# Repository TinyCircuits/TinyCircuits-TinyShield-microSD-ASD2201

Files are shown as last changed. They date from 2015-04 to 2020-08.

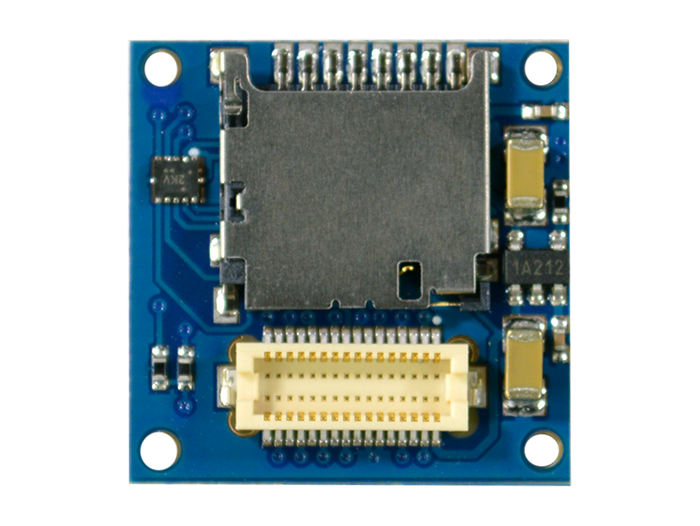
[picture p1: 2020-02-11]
images/ASD2201-R-Tutorial-Image-01.png

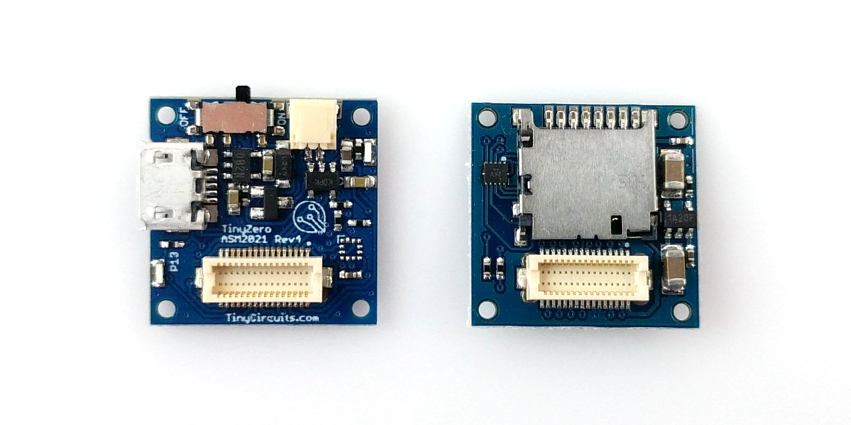
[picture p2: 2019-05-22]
images/ASD2201-R-Tutorial-Image-02.jpg

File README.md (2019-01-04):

# TinyCircuits TinyShield microSD Adapter Board
# ASD2201 Rev2

The design files are located under design_files/ for the TinyCircuits ASD2201 Rev 2 PCB.  This is a TinyShield board that has a microSD connector, local power supply and level shifters to connect to a microSD card.

Format is in Cadsoft Eagle format - Eagle version 6.2 was used for the original design.

For more infomation on this, check out the product page at TinyCircuits.com: https://tinycircuits.com/collections/memory/products/microsd-tinyshield

# License:

Design by TinyCircuits.
All design files are released under the Creative Commons Attribution Share-Alike 3.0 License, see the following link for details: http://creativecommons.org/licenses/by-sa/3.0

All text above must be included in any redistribution or derived design

This project uses designs and concepts developed as part of the Arduino project and the LilyPad project.  The TinyCircuits design files themselves (schematics, PCB and libraries) are not directly derived from these works' design files and have been created new, however the concepts and basic architecture behind the TinyDuino and TinyLily products are derived and we thank the hard work of the organizations below for their contributions to open-source hardware:
  
Original Arduino Uno Design by Team Arduino

LilyPad Arduino Design by Leah Buechley and Sparkfun Electronics

Please support the open-source hardware community

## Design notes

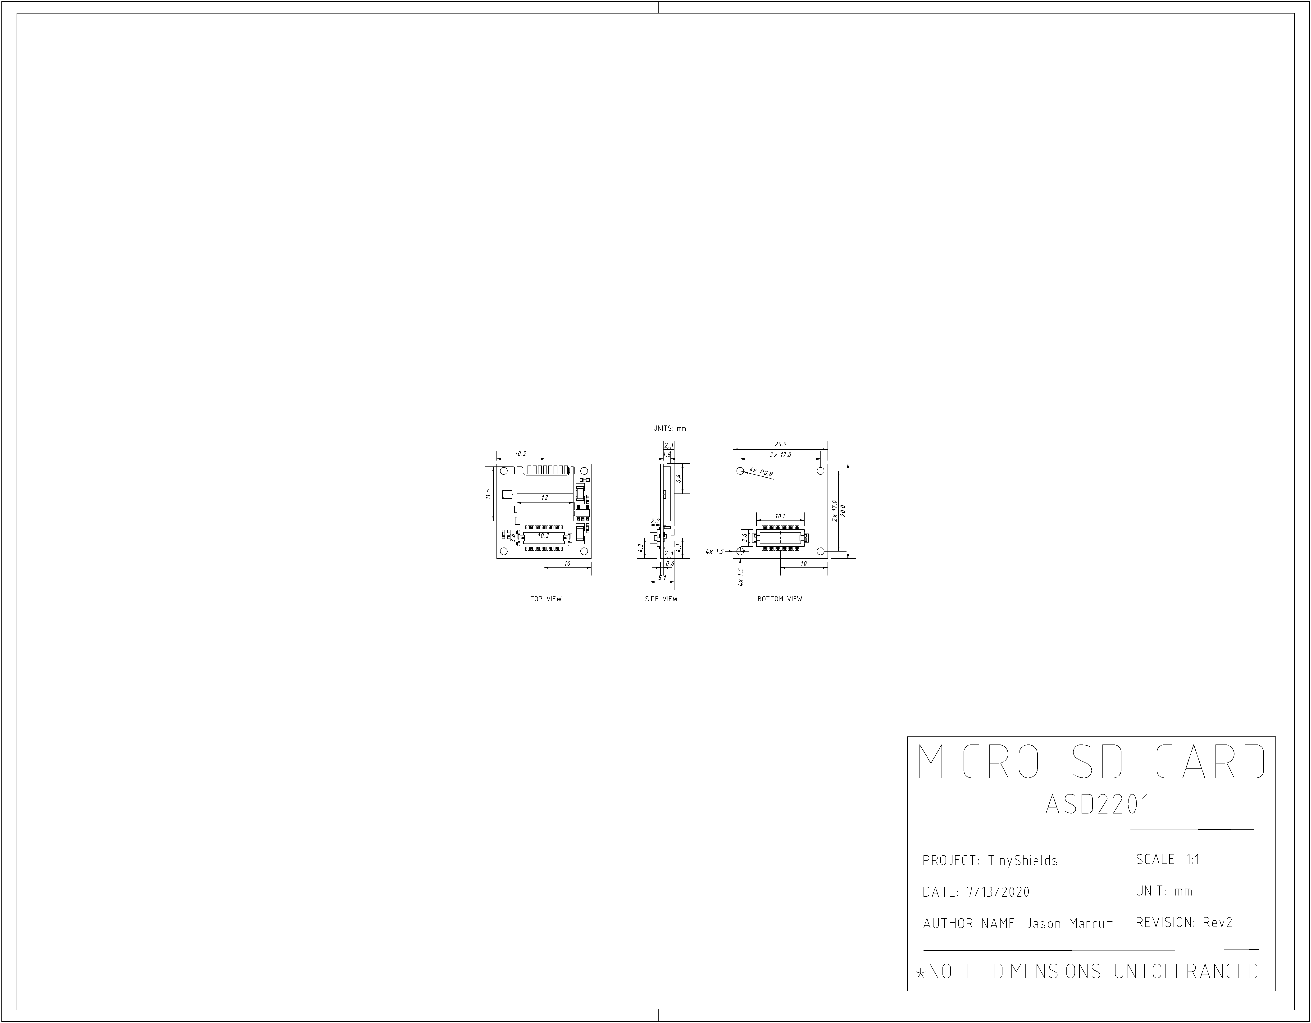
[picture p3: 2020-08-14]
cad/TinyShield_SDCARD_ASD2201_REV2-DETAILED_DRAWING-PNG.png

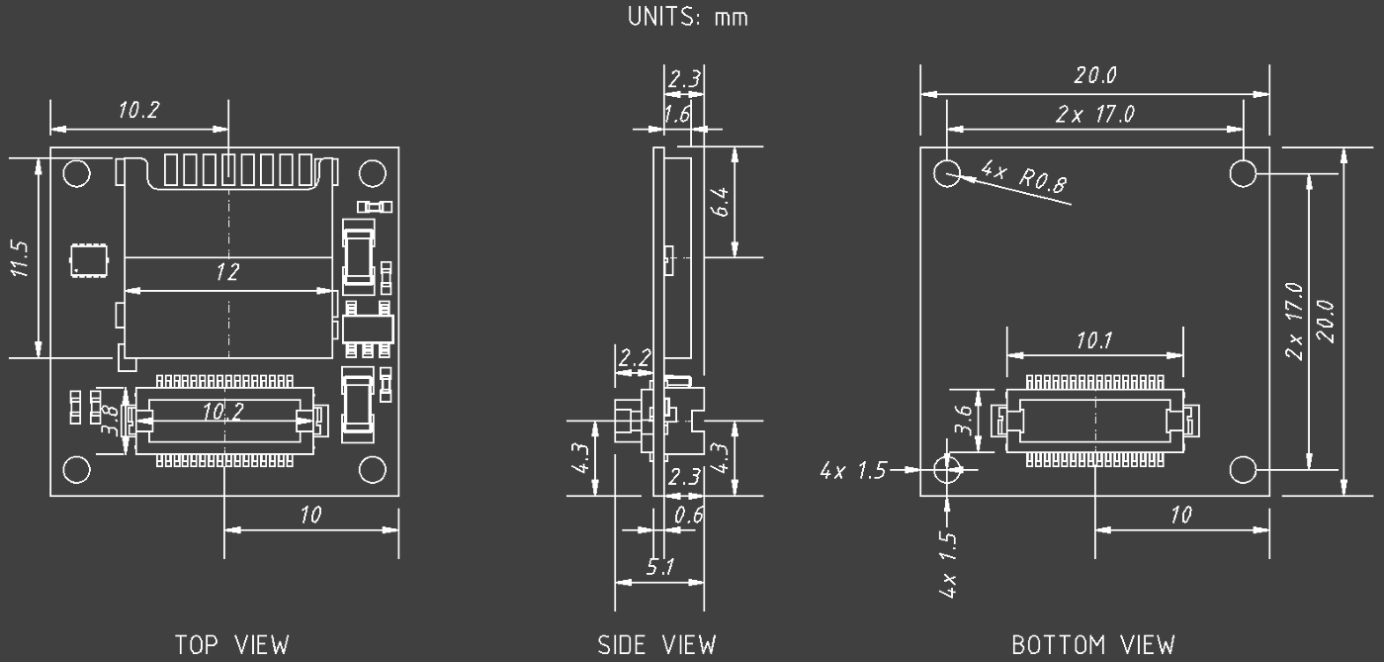
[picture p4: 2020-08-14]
cad/TinyShield_SDCARD_ASD2201_REV2-DETAILED_DRAWING_COMPACT-PNG.png

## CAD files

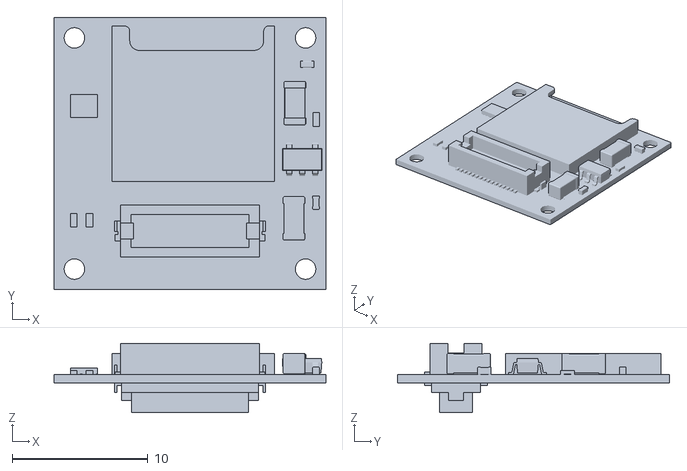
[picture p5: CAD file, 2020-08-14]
cad/TinyShield_SDCARD_ASD2201_REV2-STL.stl
20.0 x 20.0 x 5.10

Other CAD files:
cad/TinyShield_SDCARD_ASD2201_REV2-DETAILED_DRAWING-DXF.dxf

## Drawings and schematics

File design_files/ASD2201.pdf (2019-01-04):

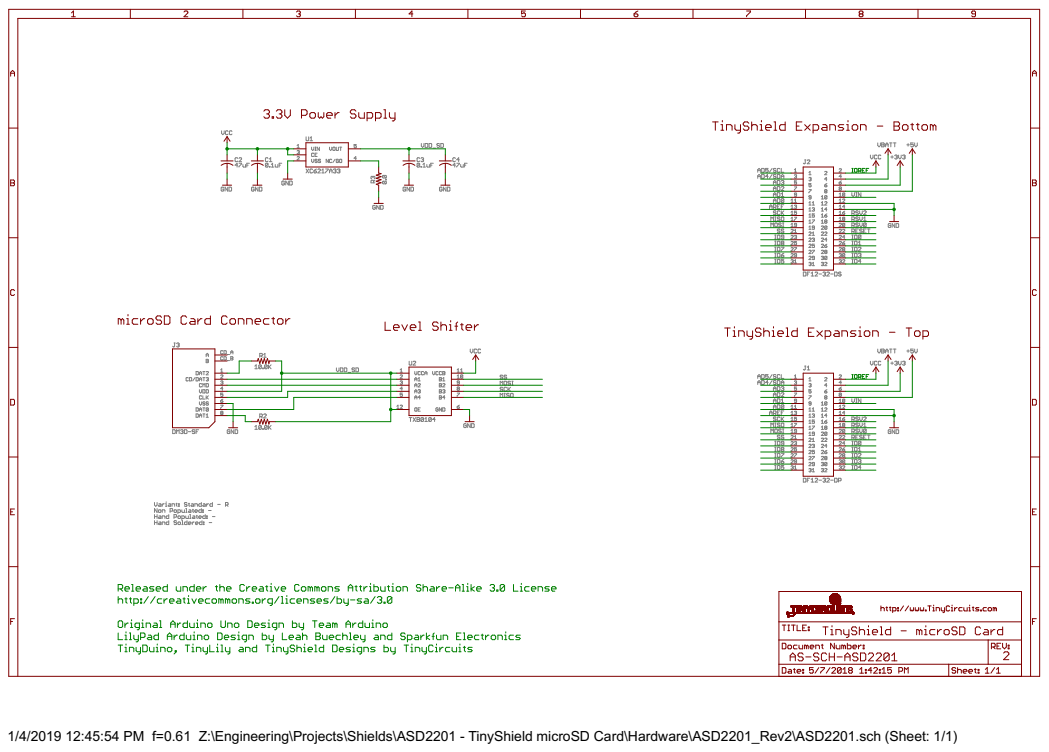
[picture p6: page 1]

1/4/2019 12:45:54 PM f=0.61 Z:\Engineering\Projects\Shields\ASD2201 - TinyShield microSD Card\Hardware\ASD2201_Rev2\ASD2201.sch (Sheet: 1/1)

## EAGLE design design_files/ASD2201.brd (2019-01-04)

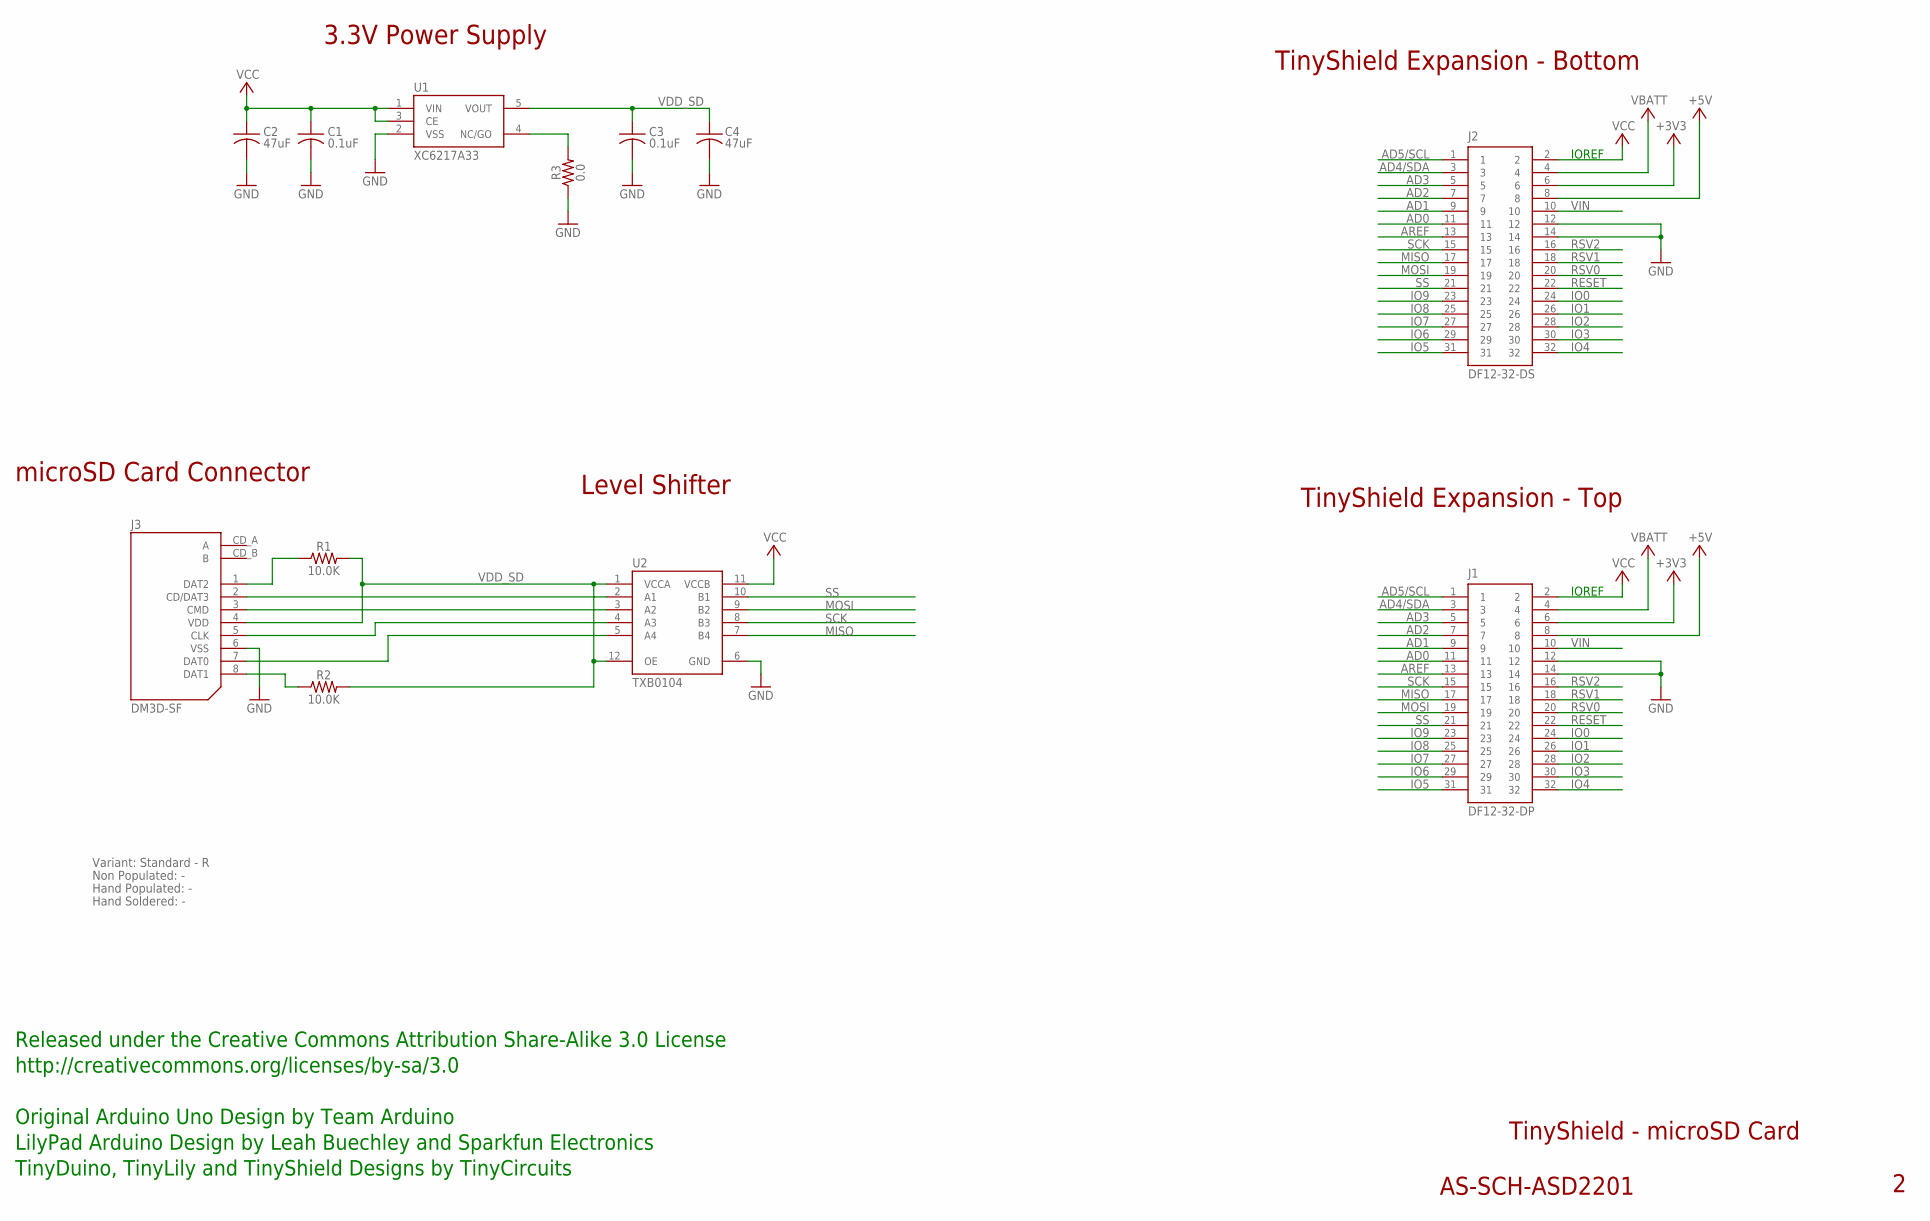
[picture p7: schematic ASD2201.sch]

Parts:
C1, C3: 0.1uF; C0402; PARTNO AS-ITM-00008
C2, C4: 47uF; C1206
J1: DF12-32-DP; PARTNO AS-ITM-00015
J2: DF12-32-DS; PARTNO AS-ITM-00012
J3: DM3D-SF; SD_CARD
R1, R2: 10.0K; 0402
R3: 0.0; 0402
U1: XC6217A33; SOT-25; PARTNO AS-ITM-00249
U2: TXB0104; UQFN-12

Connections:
+3V3: J1.6, J2.6
+5V: J1.8, J2.8
AD0: J1.11, J2.11
AD1: J1.9, J2.9
AD2: J1.7, J2.7
AD3: J1.5, J2.5
AD4/SDA: J1.3, J2.3
AD5/SCL: J1.1, J2.1
AREF: J1.13, J2.13
GND: C1.2, C2.2, C3.2, C4.2, J1.12, J1.14, J2.12, J2.14, J3.6 (VSS), R3.1, U1.2 (VSS), U2.6 (GND)
IO0: J1.24, J2.24
IO1: J1.26, J2.26
IO2: J1.28, J2.28
IO3: J1.30, J2.30
IO4: J1.32, J2.32
IO5: J1.31, J2.31
IO6: J1.29, J2.29
IO7: J1.27, J2.27
IO8: J1.25, J2.25
IO9: J1.23, J2.23
MISO: J1.17, J2.17, U2.7 (B4)
MOSI: J1.19, J2.19, U2.9 (B2)
unnamed: J3.1 (DAT2), R1.1
unnamed: J3.8 (DAT1), R2.1
unnamed: J3.2 (CD/DAT3), U2.2 (A1)
unnamed: J3.3 (CMD), U2.3 (A2)
unnamed: J3.5 (CLK), U2.4 (A3)
unnamed: J3.7 (DAT0), U2.5 (A4)
unnamed: R3.2, U1.4 (NC/GO)
RESET: J1.22, J2.22
RSV0: J1.20, J2.20
RSV1: J1.18, J2.18
RSV2: J1.16, J2.16
SCK: J1.15, J2.15, U2.8 (B3)
SS: J1.21, J2.21, U2.10 (B1)
VBATT: J1.4, J2.4
VCC: C1.1, C2.1, J1.2, J2.2, U1.1 (VIN), U1.3 (CE), U2.11 (VCCB)
VDD_SD: C3.1, C4.1, J3.4 (VDD), R1.2, R2.2, U1.5 (VOUT), U2.1 (VCCA), U2.12 (OE)
VIN: J1.10, J2.10

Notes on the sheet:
TinyShield Expansion - Bottom
TinyShield - microSD Card
AS-SCH-ASD2201
TinyShield Expansion - Top
IOREF
Released under the Creative Commons Attribution Share-Alike 3.0 License
http://creativecommons.org/licenses/by-sa/3.0
LilyPad Arduino Design by Leah Buechley and Sparkfun Electronics
TinyDuino, TinyLily and TinyShield Designs by TinyCircuits
Original Arduino Uno Design by Team Arduino
3.3V Power Supply
Level Shifter
microSD Card Connector
Non Populated: -
Hand Populated: -
Hand Soldered: -
Variant: Standard - R

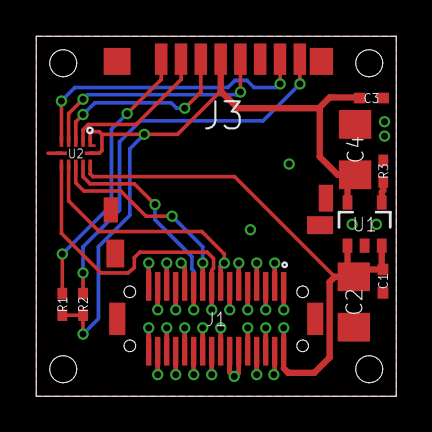
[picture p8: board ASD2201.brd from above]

Board: 2 copper layers, 20.0 x 20.0 mm, 13 parts (1 on the bottom side), 39 nets.

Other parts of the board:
U$1: DOCFIELD-TINYCIRCUITS-PCB

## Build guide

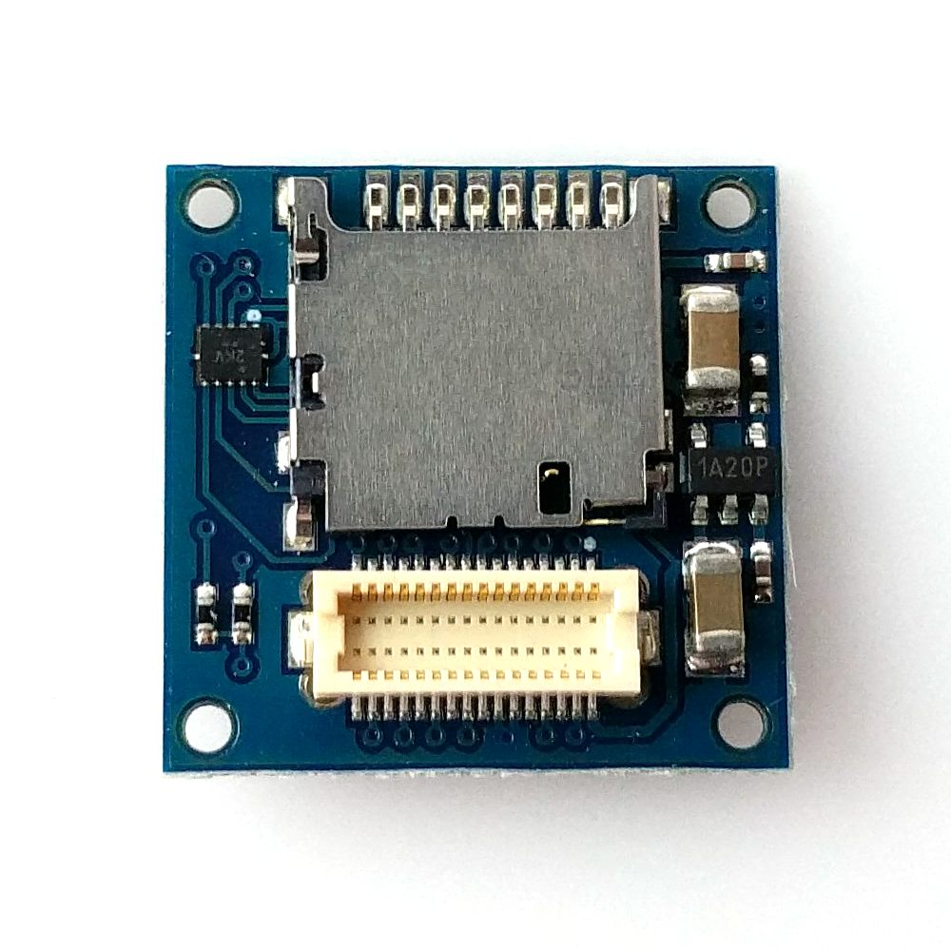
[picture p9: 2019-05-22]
images/ASD2201-R-Tutorial-Image-01.jpg

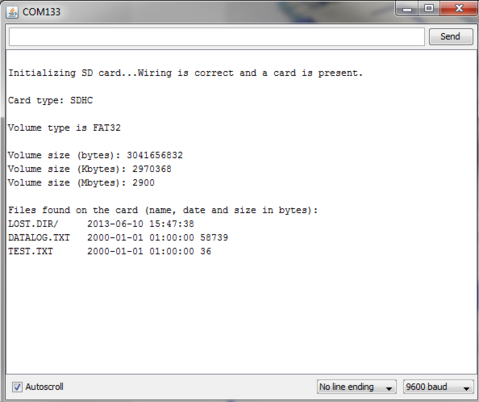
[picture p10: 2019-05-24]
images/ASD2201-R-Tutorial-Image-06.png

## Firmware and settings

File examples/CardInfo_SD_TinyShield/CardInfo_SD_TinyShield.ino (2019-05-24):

/*
  SD card test

  This example shows how use the utility libraries on which the'
  SD library is based in order to get info about your SD card.
  Very useful for testing a card when you're not sure whether its working or not.

  The circuit:
    SD card attached to SPI bus as follows:
 ** MOSI - pin 11 on Arduino Uno/Duemilanove/Diecimila
 ** MISO - pin 12 on Arduino Uno/Duemilanove/Diecimila
 ** CLK - pin 13 on Arduino Uno/Duemilanove/Diecimila
 ** CS - depends on your SD card shield or module.
 		Pin 4 used here for consistency with other Arduino examples


  created  28 Mar 2011
  by Limor Fried
  modified 9 Apr 2012
  by Tom Igoe

  modified 24 May 2019
  by Laveréna Wienclaw for TinyCircuits 
*/
// include the SD library:
#include <SPI.h>
#include <SD.h>

// set up variables using the SD utility library functions:
Sd2Card card;
SdVolume volume;
SdFile root;

// change this to match your SD shield or module;
// Arduino Ethernet shield: pin 4
// Adafruit, and TinyCircuits SD shields and modules: pin 10
// Sparkfun SD shield: pin 8
// MKRZero SD: SDCARD_SS_PIN
const int chipSelect = 10;

// Make program compatibile for all TinyCircuits processor boards
#if defined(ARDUINO_ARCH_SAMD)
  #define SerialMonitor SerialUSB
#else
  #define SerialMonitor Serial
#endif

void setup() {
  // Open serial communications and wait for port to open:
  SerialMonitor.begin(9600);
  while (!SerialMonitor) {
    ; // wait for serial port to connect. Needed for native USB port only
  }


  SerialMonitor.print("\nInitializing SD card...");

  // we'll use the initialization code from the utility libraries
  // since we're just testing if the card is working!
  if (!card.init(SPI_HALF_SPEED, chipSelect)) {
    SerialMonitor.println("initialization failed. Things to check:");
    SerialMonitor.println("* is a card inserted?");
    SerialMonitor.println("* is your wiring correct?");
    SerialMonitor.println("* did you change the chipSelect pin to match your shield or module?");
    while (1);
  } else {
    SerialMonitor.println("Wiring is correct and a card is present.");
  }

  // print the type of card
  SerialMonitor.println();
  SerialMonitor.print("Card type:         ");
  switch (card.type()) {
    case SD_CARD_TYPE_SD1:
      SerialMonitor.println("SD1");
      break;
    case SD_CARD_TYPE_SD2:
      SerialMonitor.println("SD2");
      break;
    case SD_CARD_TYPE_SDHC:
      SerialMonitor.println("SDHC");
      break;
    default:
      SerialMonitor.println("Unknown");
  }

  // Now we will try to open the 'volume'/'partition' - it should be FAT16 or FAT32
  if (!volume.init(card)) {
    SerialMonitor.println("Could not find FAT16/FAT32 partition.\nMake sure you've formatted the card");
    while (1);
  }

  SerialMonitor.print("Clusters:          ");
  SerialMonitor.println(volume.clusterCount());
  SerialMonitor.print("Blocks x Cluster:  ");
  SerialMonitor.println(volume.blocksPerCluster());

  SerialMonitor.print("Total Blocks:      ");
  SerialMonitor.println(volume.blocksPerCluster() * volume.clusterCount());
  SerialMonitor.println();

  // print the type and size of the first FAT-type volume
  uint32_t volumesize;
  SerialMonitor.print("Volume type is:    FAT");
  SerialMonitor.println(volume.fatType(), DEC);

  volumesize = volume.blocksPerCluster();    // clusters are collections of blocks
  volumesize *= volume.clusterCount();       // we'll have a lot of clusters
  volumesize /= 2;                           // SD card blocks are always 512 bytes (2 blocks are 1KB)
  SerialMonitor.print("Volume size (Kb):  ");
  SerialMonitor.println(volumesize);
  SerialMonitor.print("Volume size (Mb):  ");
  volumesize /= 1024;
  SerialMonitor.println(volumesize);
  SerialMonitor.print("Volume size (Gb):  ");
  SerialMonitor.println((float)volumesize / 1024.0);

  SerialMonitor.println("\nFiles found on the card (name, date and size in bytes): ");
  root.openRoot(volume);

  // list all files in the card with date and size
  root.ls(LS_R | LS_DATE | LS_SIZE);
}

void loop(void) {
}

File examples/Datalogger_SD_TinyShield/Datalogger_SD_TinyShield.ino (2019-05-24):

/*
  SD card datalogger

 This example shows how to log data from three analog sensors
 to an SD card using the SD library.

 The circuit:
 * analog sensors on analog ins 0, 1, and 2
 * SD card attached to SPI bus as follows:
 ** MOSI - pin 11
 ** MISO - pin 12
 ** CLK - pin 13
 ** CS - pin 4 (for MKRZero SD: SDCARD_SS_PIN)

 created  24 Nov 2010
 modified 9 Apr 2012
 by Tom Igoe

 modified 24 May 2019
 Adapted for TinyCircuits SD Card TinyShield, by Laveréna Wienclaw

 This example code is in the public domain.

 */

#include <SPI.h>
#include <SD.h>

// Changed from 4 to make compatible with TinyCircuits hardware
const int chipSelect = 10;

// Make program compatibile for all TinyCircuits processor boards
#if defined(ARDUINO_ARCH_SAMD)
  #define SerialMonitor SerialUSB
#else
  #define SerialMonitor Serial
#endif

void setup() {
  // Open serial communications and wait for port to open:
  SerialMonitor.begin(9600);
  while (!SerialMonitor) {
    ; // wait for serial port to connect. Needed for native USB port only
  }


  SerialMonitor.print("Initializing SD card...");

  // see if the card is present and can be initialized:
  if (!SD.begin(chipSelect)) {
    SerialMonitor.println("Card failed, or not present");
    // don't do anything more:
    while (1);
  }
  SerialMonitor.println("card initialized.");
}

void loop() {
  // make a string for assembling the data to log:
  String dataString = "";

  // read three sensors and append to the string:
  for (int analogPin = 0; analogPin < 3; analogPin++) {
    int sensor = analogRead(analogPin);
    dataString += String(sensor);
    if (analogPin < 2) {
      dataString += ",";
    }
  }

  // open the file. note that only one file can be open at a time,
  // so you have to close this one before opening another.
  File dataFile = SD.open("datalog.txt", FILE_WRITE);

  // if the file is available, write to it:
  if (dataFile) {
    dataFile.println(dataString);
    dataFile.close();
    // print to the serial port too:
    SerialMonitor.println(dataString);
  }
  // if the file isn't open, pop up an error:
  else {
    SerialMonitor.println("error opening datalog.txt");
  }
}

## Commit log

2015-04-11 Update for Rev 2 Design
    [ASD2201.brd, ASD2201.sch]
2019-01-04 update format
    [ASD2201.brd, ASD2201.sch]
2020-08-14 Add CAD data
    [TinyShield_SDCARD_ASD2201_REV2-DETAILED_DRAWING-DXF.dxf, TinyShield_SDCARD_ASD2201_REV2-STL.stl]
